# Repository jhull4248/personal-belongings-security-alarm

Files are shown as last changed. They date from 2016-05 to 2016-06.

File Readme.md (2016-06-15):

# Personal-belongings-security-alarm
author: Jonathan Hull  
date: May 24, 2016  

This repository contains files for a term project on building the RC feedback oscillator shown in the following schematic.  This was the final project in ENGR12L, Engineering Circuits Lab, at Monterey Peninsula College in the Spring 2016 semester.  

schematic 050116

The primary feature of the circuit is an RC phase shift oscillator that should produce a sine wave of about 4 kHz.  The circuit is inactive until a short circuit to ground is removed at which time a distinctive sound is emitted.  Conceptually, the wire that shorts the circuit could be attached to an item in someone's pocket and the alarm would sound if the item is removed by a thief. 

# Theoretical background

The circuit in this project generates a sine wave by looping a current through a feedback network comprised of three RC stages.  Each stage generates a 60 degree phase shift.  The result is passed to the inverting input of the opamp that provides another 180 degrees of phase shift.  The 360 degrees of phase shift plus sufficient gain from the opamp guarantees that the circuit will produce a continuous sine wave [4].  Theoretical analysis of the circuit predicts that f = sqrt(6)/(2*pi*R*C) = 3898 Hz when R=1k ohms and C=100 nF [5].

# Project steps

The project was started in late April with a target completion date of June 2, 2016.  The first step was implementation of the design in circuitlab.  This helped in understanding the circuit but unfortunately a model for the LM380 opamp could not be located and thus circuitlab could not run simulations.  Nevertheless, circuitlab does contain links that were quite useful in ordering the components needed to build a prototype.

The prototype shown below was constructed with the 14 pin version of the LM380 because it was readily available.   The prototype was initially tested with a 6V power supply because [2] indicated that it was the preferred choice.  However, that did not work correctly and a 9V supply was adopted after we observed that it was used in [1].  

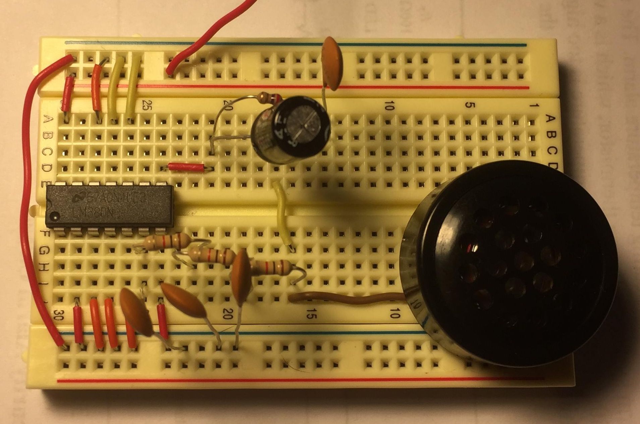
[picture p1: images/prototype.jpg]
breadboard prototype 050816


An additional goal of building a printed circuit board (PCB) for the circuit was pursued at the author's own volition.  Some brief web searching showed that building a PCB requires two steps: design with a software package and sending Gerber files to a PCB manufacturer.  The manufacturer uses the Gerber files to produce the board.  After it's returned, the components are soldered onto it.

After some analysis of the available alternatives, the Eagle software PCB design package was chosen because of its popularity in the Arduino community and the fact that it's free for educational purposes.  Eagle requires the user to provide a schematic and it creates a corresponding design for a PCB.  The design shows where components are placed on the board and the precise location of tracks between each component.  The tracks correspond to wires in the prototype that will become copper traces on the PCB.

The Eagle package was relatively straightforward to use because of the excellent directions in [3].  Within a day, the following design for a 5x5cm two-layer board was complete.  The components and holes for their wires are also shown as well as the traces between holes.  The brown traces are on the top layer of the board.  The blue traces are on the bottom.

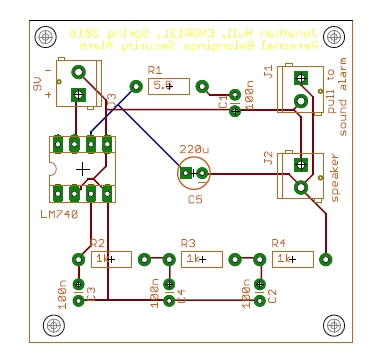
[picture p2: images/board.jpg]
board layout


The Eagle package also outputs Gerber files.  After getting quotes from three vendors, [itead.cc](http://itead.cc) was chosen because they agreed to produce 12 "bare boards" (without components soldered on) for $9.90.  The Gerber files were uploaded to their web site on Friday May 13 and the boards were delivered on Monday May 23.  Both sides of the bare board that itead produced are shown below.

The boards were ordered from itead as a two layer PCB, 5cm x 5cm max, 1.6mm thick, HASL surface finish, 100% E-test, and 1 oz. thick copper.  The traces were 10mil wide with 20mil minimum space between traces.  These are normal parameters and were perfectly adequate for this design.

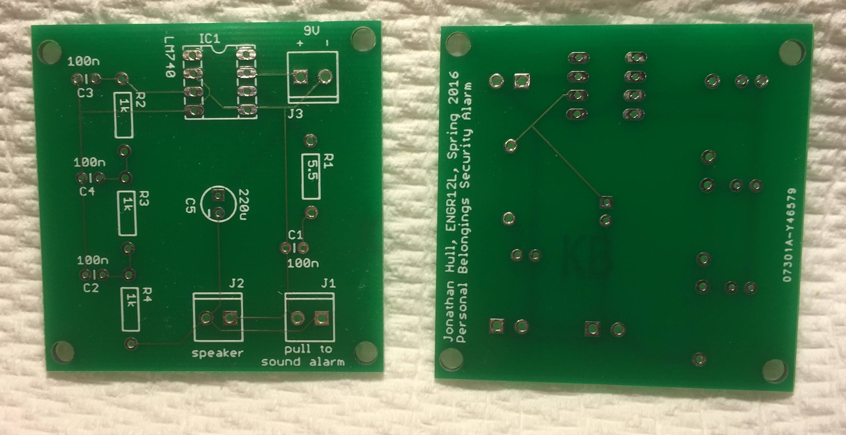
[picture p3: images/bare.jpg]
bare


The final version of the board shown below was produced by soldering the components on one of the bare boards.  Happily, this worked correctly the first time.  Needless to say, this was a huge relief since a mistake could only be corrected with another ten day turnaround from itead.

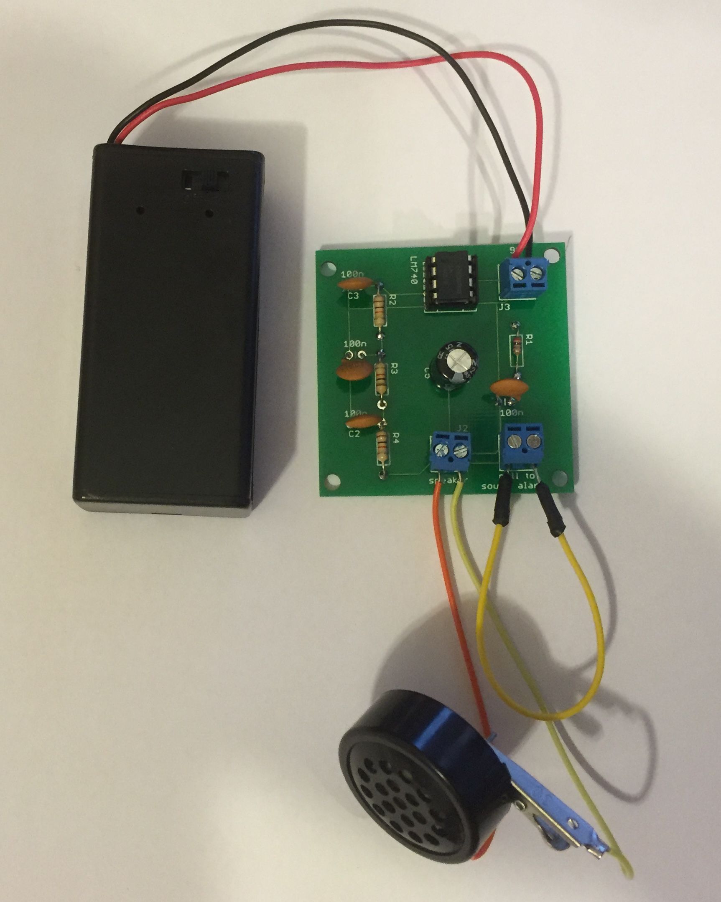
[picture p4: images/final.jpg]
final

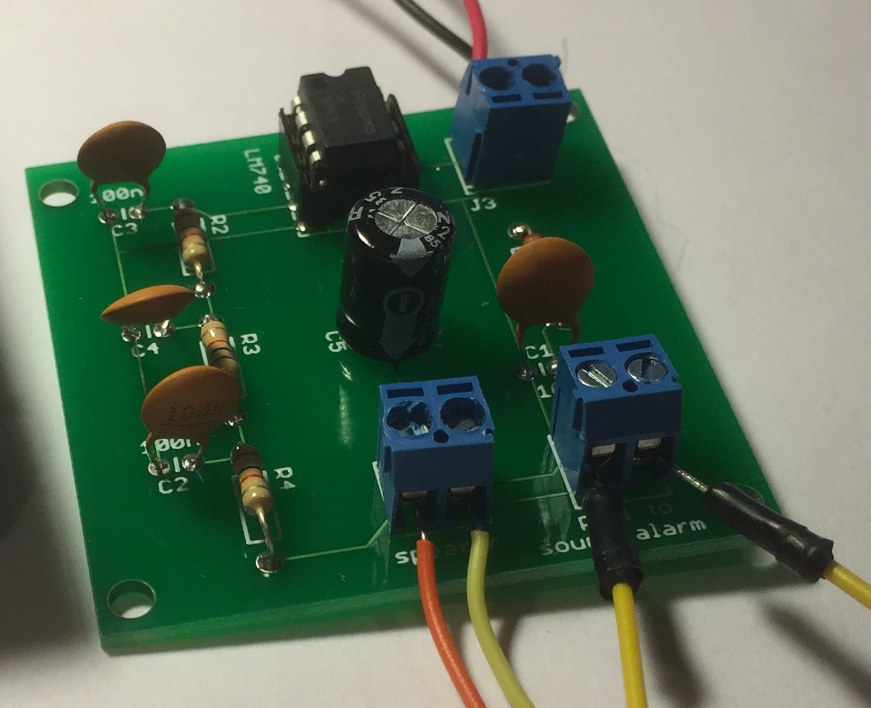
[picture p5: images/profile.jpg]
profile view


# Experimental Results

Verification of the theoretical prediction that the circuit would produce a 4 kHz sine wave was done by connecting the first channel of the Digilent Analog Discovery 2 USB oscilloscope to the speaker terminals.  The voltage trace is shown below.  We see a waveform that's shaped like a sine wave, but not as smooth as it should be.  The frequency of the waveform is 4.09 kHz which is within about 4.8% ((|3898-4087|/3898)*100) of the theoretically predicted value of 3.90 kHz.  A video illustrating the operation of the circuit is available at https://youtu.be/Xsj34tHOlkY

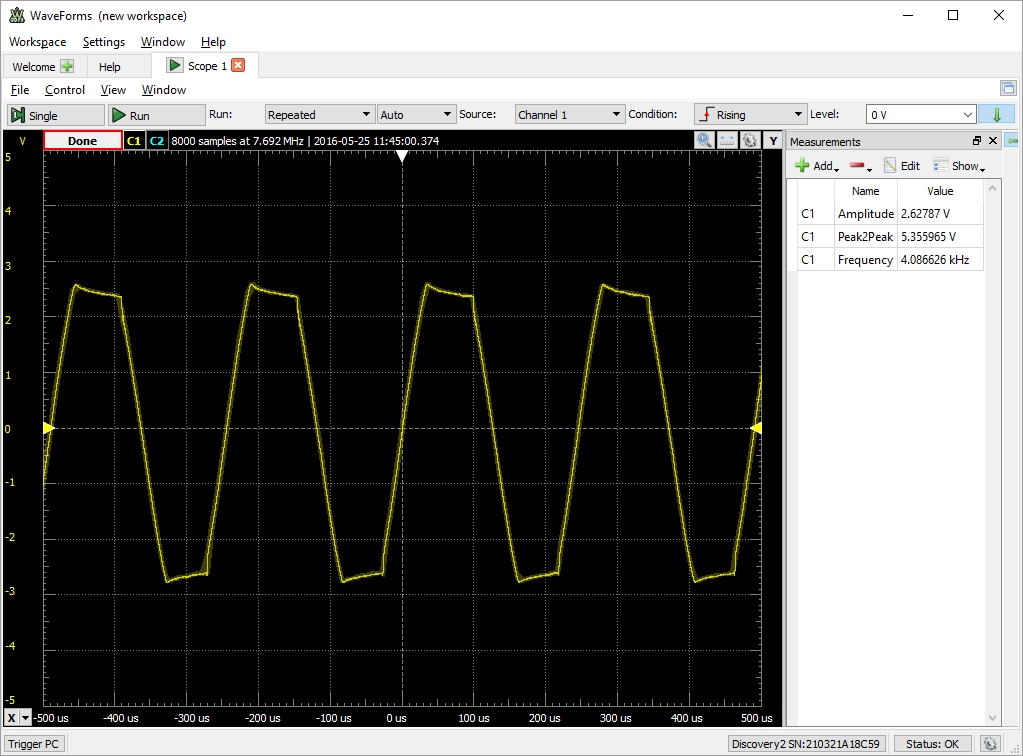
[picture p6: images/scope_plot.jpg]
scope plot


# Files

The Eagle schematic, board file and Gerber files in the format required by itead are in this github repository.

# Conclusions

This project shows how a sine wave can be generated with a handful of low cost components and is an excellent example of a circuit with practical applications.  Production of the PCB was an interesting addition to the project that shows how an abstract design expressed in a schematic can be reduced to a form that could be used in a real product.  First hand knowledge of this process is something that every electrical enginer and computer scientist should have as they progress through their career and imagine different ways in which their ideas could end up in a product that normal people would pay for.  A printed circuit board is one way that could happen.  

# References

[1].  N. Alsbou, K. Al-Olimat, V. Labay, and H. LeBlanc, "Introducing Students to Electronic Devices and Electric Circuit Applications at Early Level in the Engineering Curriculum through Multiple Projects,"  122nd ASEE Annual Conference and Exposition, Seattle, WA, June 14-17, 2015. https://www.asee.org/public/conferences/56/papers/12964/download.

[2]. "Pull Pin Security Alarm System," http://www.electronicshub.org/pull-pin-security-alarm-system/, Aug. 5, 2015.

[3].  S. Monk, Make your own PCBs with Eagle: from schematic designs to finished boards, McGraw-Hill, 2014.

[4]. Electronic Oscillators and its Feedback Network, https://www.youtube.com/watch?v=aAiZsJz4UW8&feature=youtu.be

[5]. Gate 2003 ECE Op Amp RC phase shift oscillator, https://www.youtube.com/watch?v=BdULnwS91ts&feature=youtu.be

# Additional background references

[a].  RC Phase Shift Oscillator, http://www.visionics.a.se/html/curriculum/Experiments/RC%20Phase%20Shift%20Oscillator/RC%20Phase%20Shift%20Oscillator1.html

[b].  How do Sinusoidal Oscillations Arise in RC Oscillators, https://www.researchgate.net/post/How_do_sinusoidal_oscillations_arise_in_RC_oscillators#share

[c]. What is the Basic Idea of a Wien Bridge Oscillator?, https://www.researchgate.net/post/What_is_the_basic_idea_of_Wien_bridge_oscillator_How_does_it_operate

[d]. Sine Wave Oscillator using LM741 (contains concise description of Barkhausen Criteria), http://www.engineersgarage.com/contribution/sine-wave-oscillator-using-lm741

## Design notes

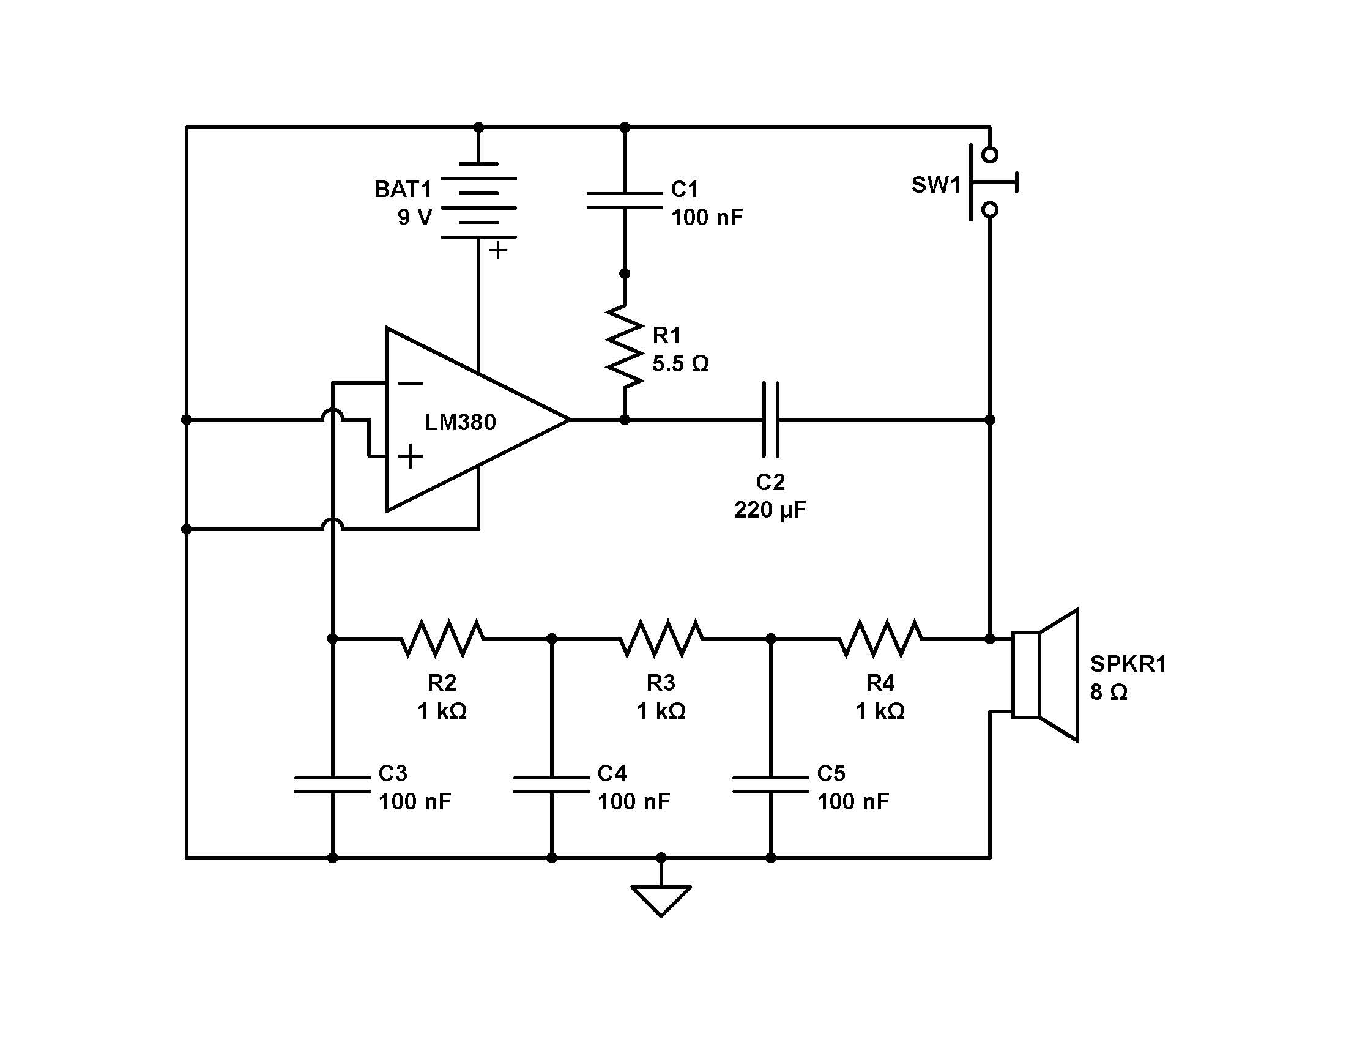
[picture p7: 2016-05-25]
images/circuit lab schematic.jpg

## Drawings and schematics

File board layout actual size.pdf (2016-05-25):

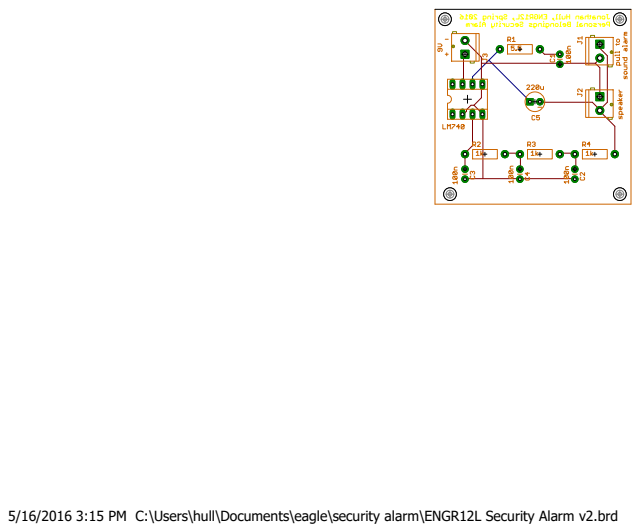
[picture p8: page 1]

5/16/2016 3:15 PM C:\Users\hull\Documents\eagle\security alarm\ENGR12L Security Alarm v2.brd

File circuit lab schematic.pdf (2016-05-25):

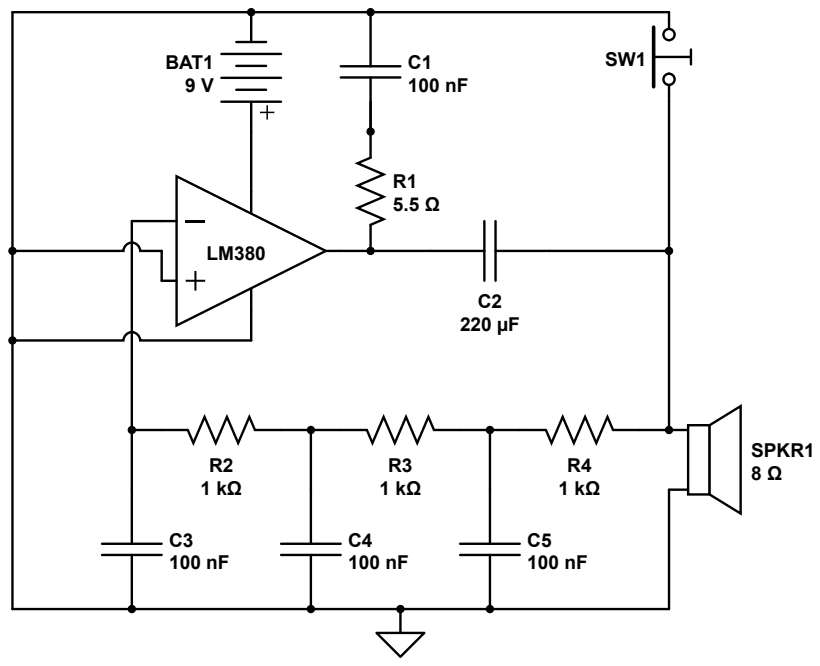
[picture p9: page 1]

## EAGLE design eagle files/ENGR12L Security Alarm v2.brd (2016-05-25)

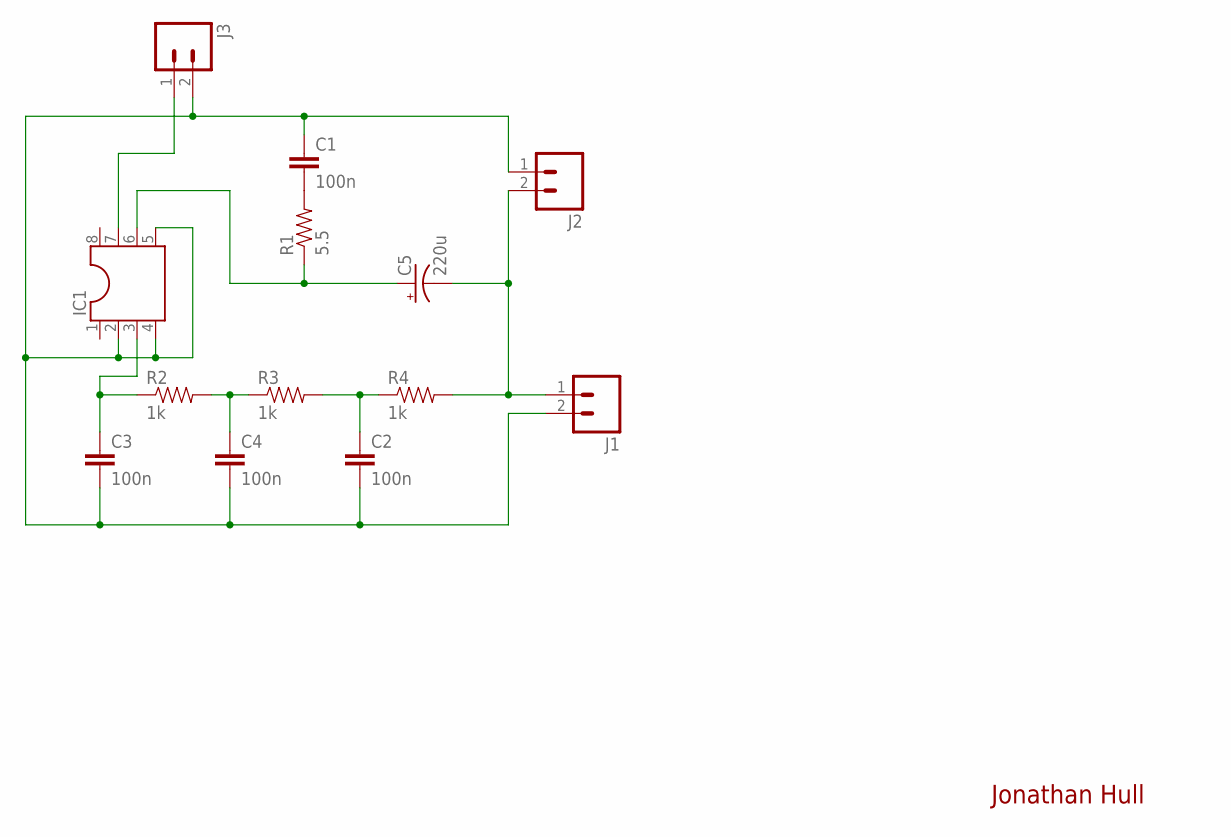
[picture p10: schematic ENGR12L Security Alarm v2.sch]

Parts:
C1, C2, C3, C4: 100n; CAP-PTH-SMALL
C5: 220u; CPOL-RADIAL-10UF-25V
IC1: DIL8S; SOCKET-08
J1, J2, J3: M023.5MM; SCREWTERMINAL-3.5MM-2
R1: 5.5; AXIAL-0.4
R2, R3, R4: 1k; AXIAL-0.4

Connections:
GND: C1.1, C2.2, C3.2, C4.2, IC1.2, IC1.4, IC1.5, J1.2, J2.1, J3.2
unnamed: C1.2, R1.P$2 (2)
unnamed: IC1.7, J3.1
unnamed: C4.1, R2.P$2 (2), R3.P$1 (1)
unnamed: C2.1, R3.P$2 (2), R4.P$1 (1)
unnamed: C3.1, IC1.3, R2.P$1 (1)
unnamed: C5.2 (-), J1.1, J2.2, R4.P$2 (2)
unnamed: C5.1 (+), IC1.6, R1.P$1 (1)

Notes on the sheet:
Jonathan Hull

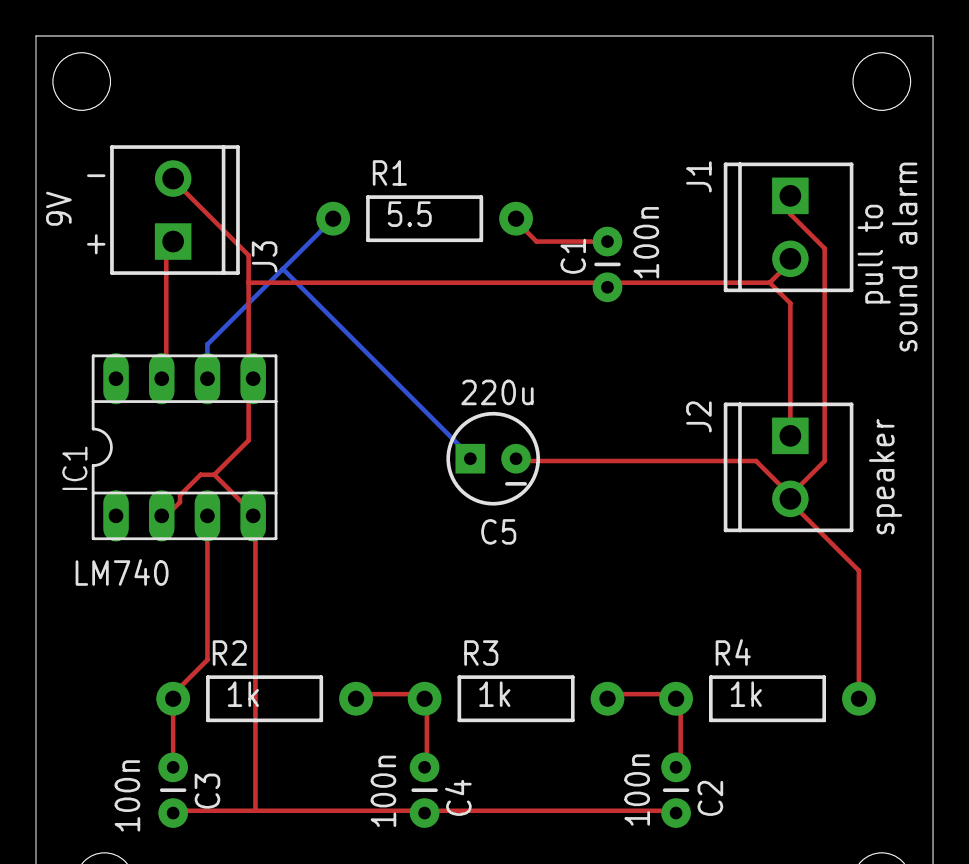
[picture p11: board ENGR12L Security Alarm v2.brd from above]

Board: 2 copper layers, 13 parts (0 on the bottom side), 8 nets.

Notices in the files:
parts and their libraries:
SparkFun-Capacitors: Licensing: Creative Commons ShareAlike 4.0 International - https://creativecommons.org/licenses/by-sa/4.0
